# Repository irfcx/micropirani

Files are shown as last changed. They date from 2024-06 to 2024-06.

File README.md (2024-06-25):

# Micropirani vacuum gauge
> [!CAUTION]
>Please bear in mind that this is **NOT** a finished thing, and I even guarantee that it will **NOT** work if you reproduce it
## What is this

This is an indirect vacuum gauge based on the thermal conductivity measuring.
Supposed to be small, cheap and easy to reproduce by using small incandescent bulbs as the pressure sensor

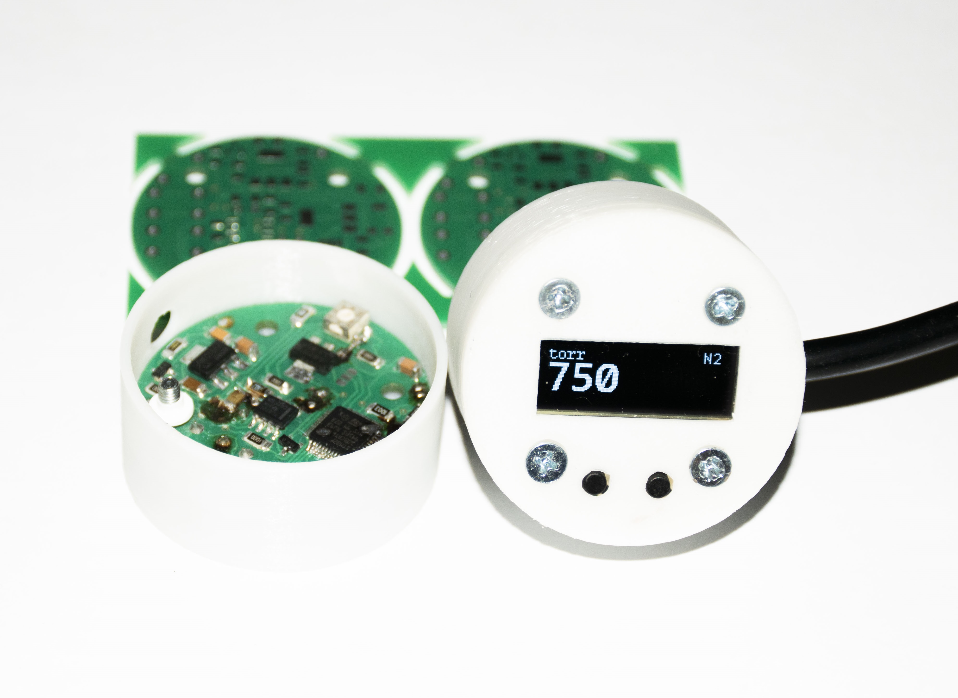
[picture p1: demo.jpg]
demo

## How it (doesn't) works

There are a lot of ways of measuring thermal conductivity, as constant current, constant voltage (or more complex) constant resistance, or even constant power stabilisation with measure of changing values.
In this case the thermal conductivity measure is based on measuring the power required to maintain constant resistance of lamp filament.
The first two (in theory) have drawbacks such as low sensitivity in high vacuum, or increased filament burning when air is rushing into the system quickly, and the last one is too complex, so i stopped on the constant resistance method.

The common CR circuit is a Wheatstone bridge with feedback on the OP. When current flows through the resistors with the same value of resistance, they are equally heated. If for some reason the resistance of one of the resistors changes, the bridge leaves the balance and the operational amplifier compensates this by changing the voltage on the bridge, which in this case is being measured.

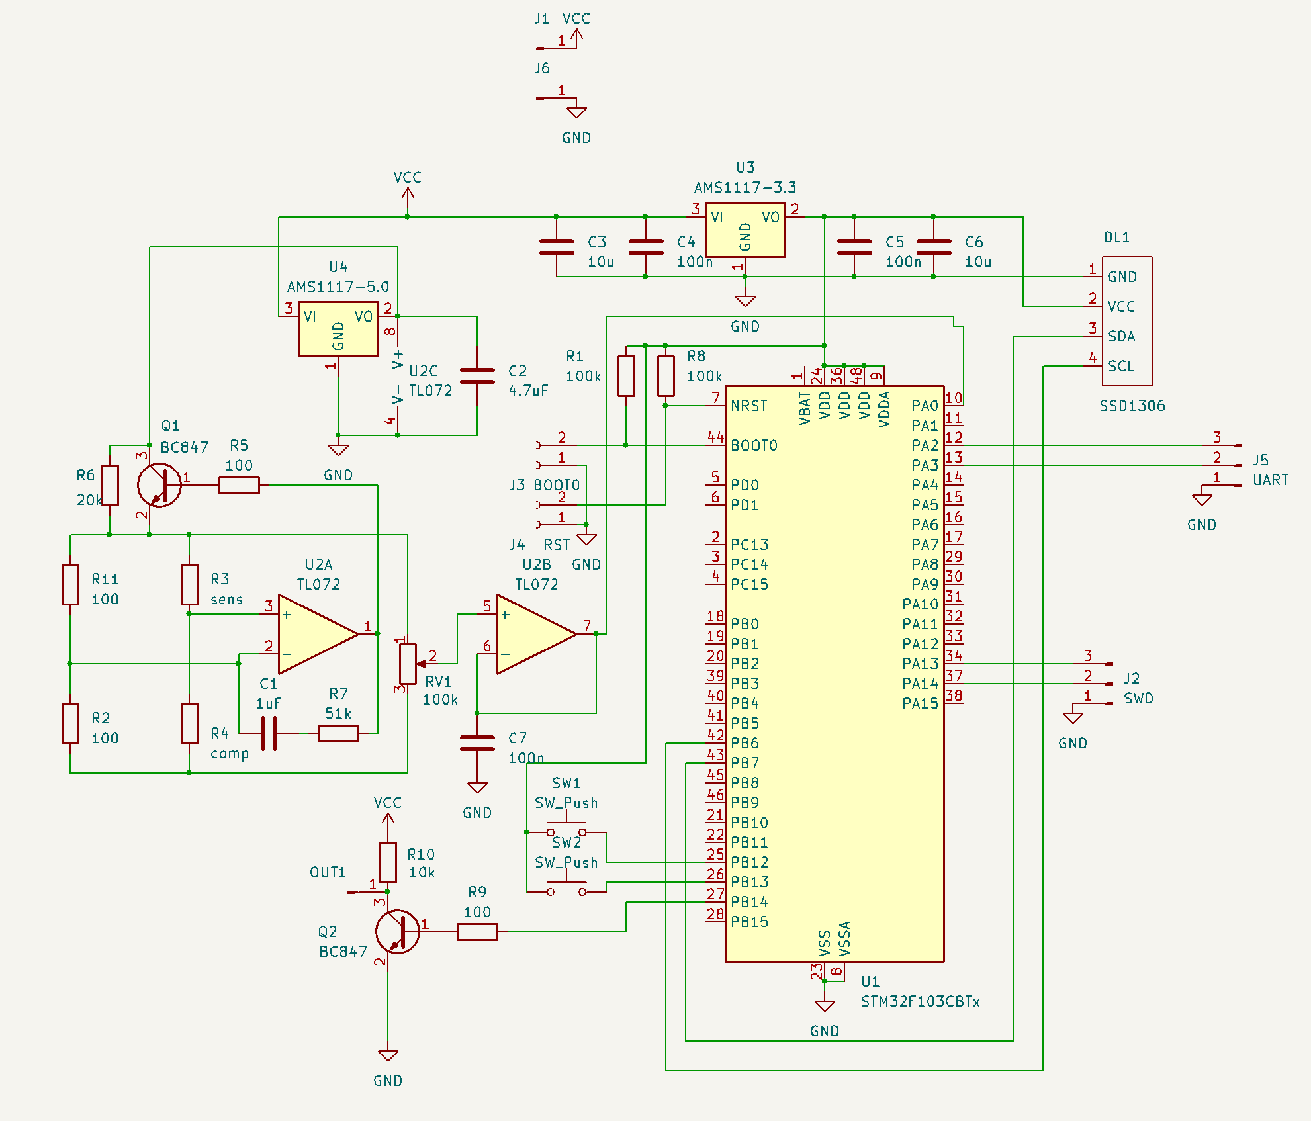
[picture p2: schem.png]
schem


As the thermal conductivity of vacuum is way lower than thermal conductivity of air, resistor (open bulb filament) is cooled less and maintaining a constant resistance requires less voltage.
To compensate the ambient temperature change, a sealed bulb is connected in series to the opened. It should be placed as close as possible to the sealed bulb. The STM32 ADC measures the voltage from the bridge that passes through the buffer (it's necessary due to the limitations of the STM's ADC) and converts it into pressure.

STM32F103CBT6 with 128 kB of flash is used as an MCU. It's also worth noting that no significant optimizations were made to reduce the code size, but the firmware still fits in the any 64 kB chip. However, due to the absence of the EEPROM, its emulation is realised using the last 127th page of the flash memory. This is an important point, because in reality even 64 kB chip has 128 kB of memory, but its operability is not declared or guaranteed by ST, so, when using smaller chips its necessary to correct the addressing.

A typical calibration curve looks like an S-curve turned on the side. However, it was not possible to find coefficients and/or digitize it with some other function, so i used the usual table and linear interpolation between points

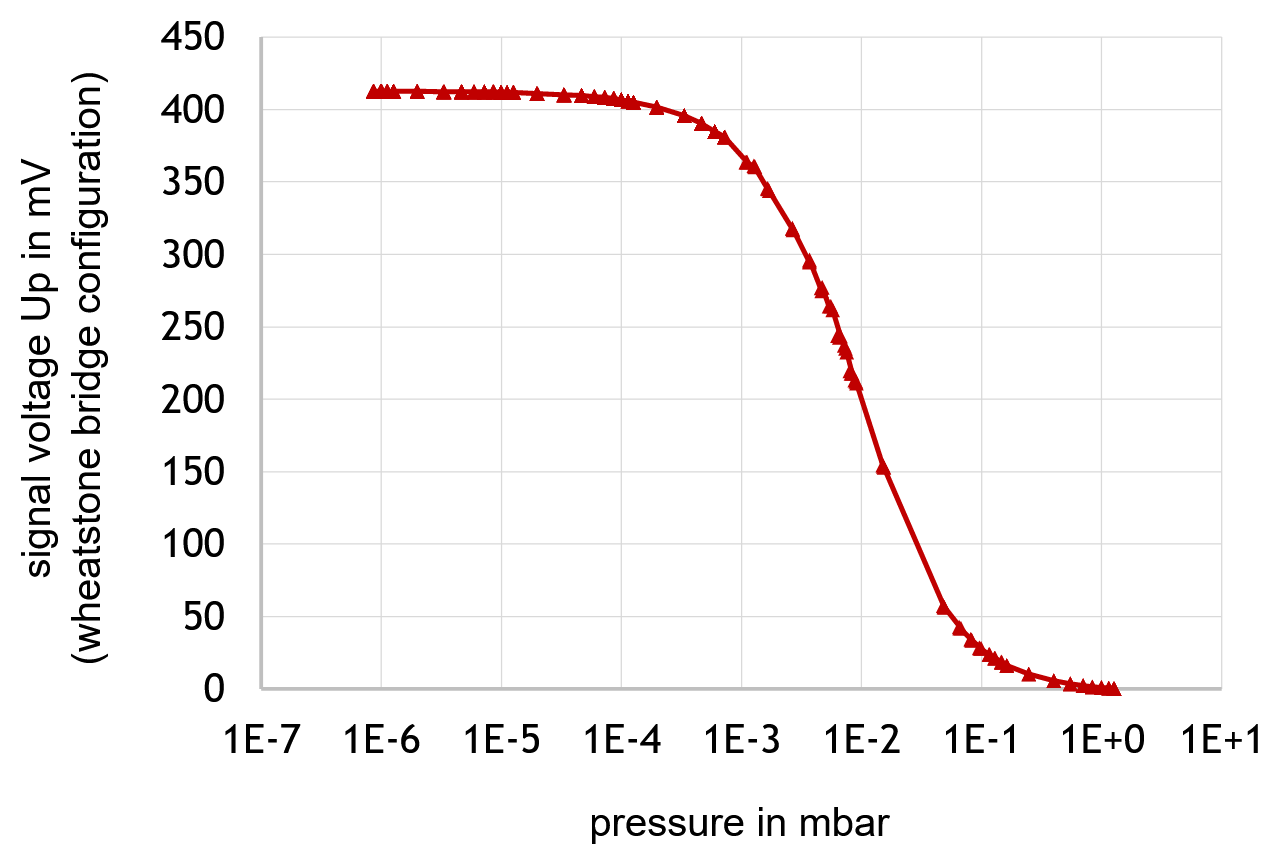
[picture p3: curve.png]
https://www.heimannsensor.com/vacuum-sensing


## Now about the mechanical part

Bulbs are glued to the custom lathe-made KF16 flange from the AISI 316 steel (despite the fact it's still a bottleneck for easy reproducing, you can replace it with cheap KF cap with the hole or whatever you want) using JB weld epoxy, which with that small expose area may be considered suitable for high vacuum

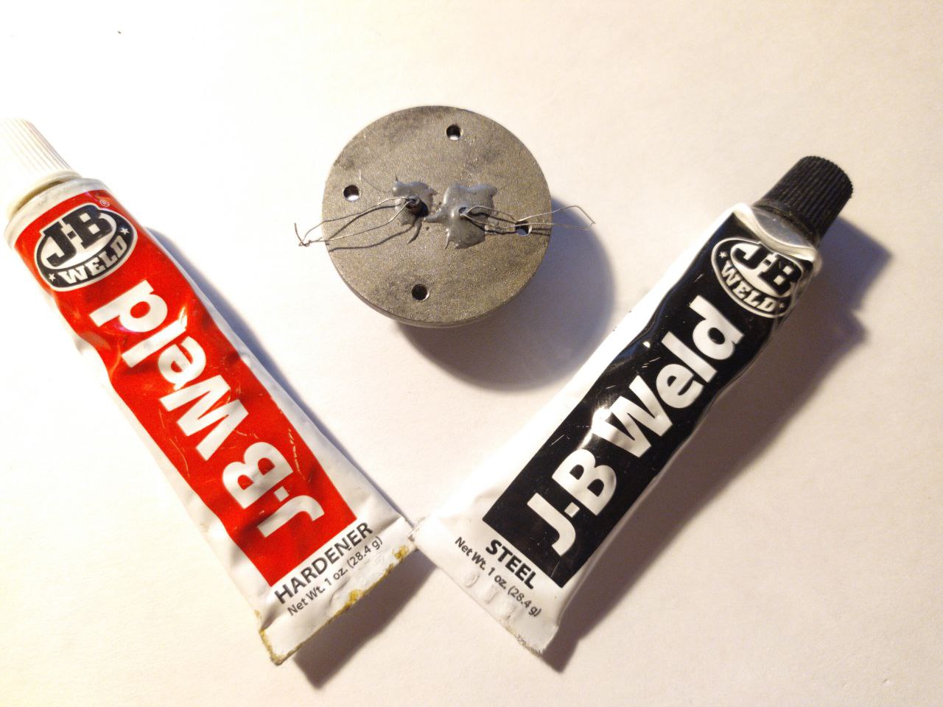
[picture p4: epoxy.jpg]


## Now about what I did wrong (and why THIS device is worse than a usual voltmeter with CC circuit)

 - As it was found experimentally, when common (12V?) light bulbs are used, the bridge voltage is changes only in range from 1.4 to 2.8 volts, which is the less than half of the ADC range, so accuracy is very low (although pirani sensors are not accurate in general), and most importantly, the lower measurement range is limited to approximately 10^-3 torr (when the theoretical limit is 10^-5 torr). As the solution, bipolar power supply for the OP can be made (in the next revision probably)
 - The dumbest thing was the use of two (!) linear voltage stabilizers and putting them in the same pcb with the bridge resistors - their heat (up to 70 C) was enough to heat the resistors so the readings drift over time and the calibration is lost when the supply voltage changes
 - The sealed (thermal compensation) bulb MUST be placed as close as possible to the open one, but for some reason they were separated by the whole centimeter of metal.
 - The lack of EM shielding causes the MCU malfunctioning near the vacuum pump when the frequency converter is used to drive the motor
 - The thickness of the metal base of the flange was insufficient so the ends of the PCB stands stick out

https://github.com/irfcx/micropirani/assets/52609749/1622802e-4848-4f7c-a10b-698a371d4f89

## File location

- Kicad pcb and schematic are located in PCB folder
- The main code is located in /source code/Core/Src/source, the main file is micropirani.h
- The compiled firmware binaries are located in /source code/Release
- In case if someone needs it, the fonts are located in /fonts

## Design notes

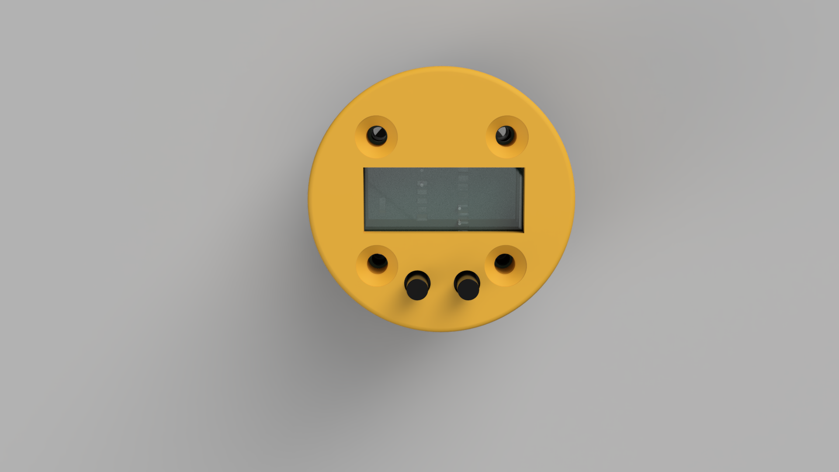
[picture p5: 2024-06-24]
render.PNG

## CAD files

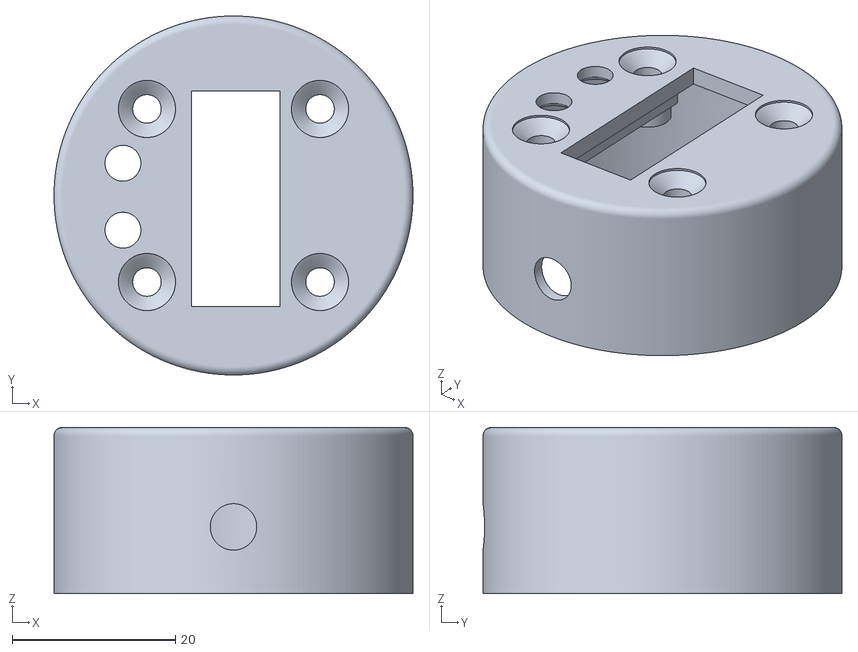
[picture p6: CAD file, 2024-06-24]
stl/Case.stl
44.0 x 44.0 x 20.4

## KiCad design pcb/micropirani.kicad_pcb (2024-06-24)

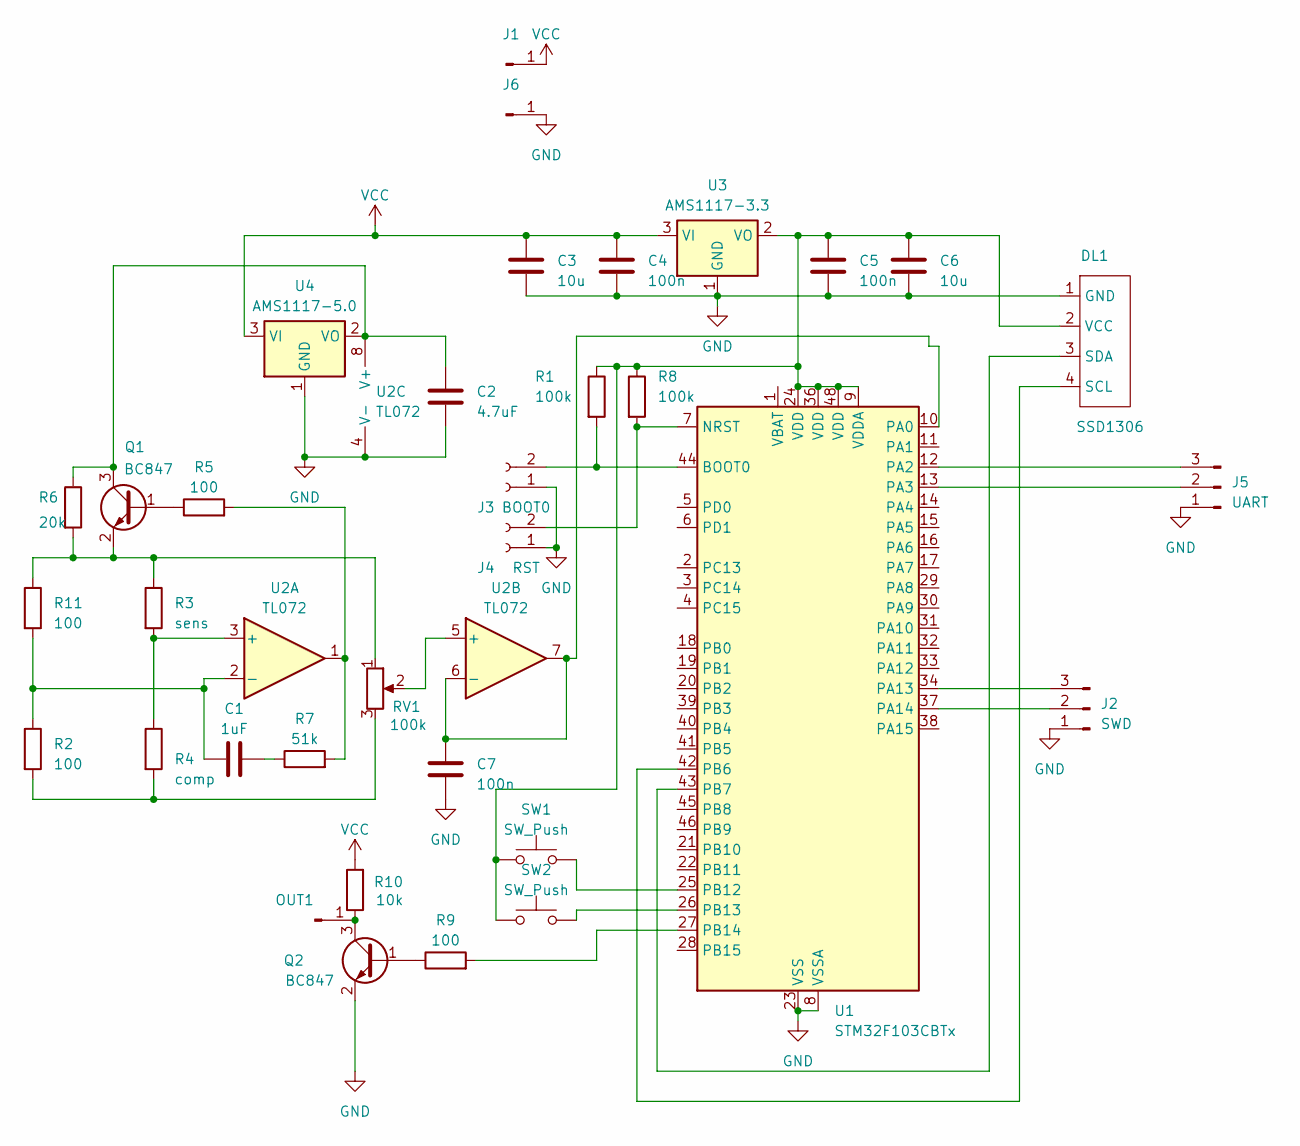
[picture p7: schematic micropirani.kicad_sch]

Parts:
C1: 1uF; C_1206_3216Metric
C2: 4.7uF; C_1206_3216Metric
C3, C6: 10u; C_1206_3216Metric
C4, C5, C7: 100n; C_1206_3216Metric
DL1: SSD1306
J1, J6: Conn_01x01_Pin; TestPoint_THTPad_D2.0mm_Drill1.0mm
J2: SWD; SolderJumper-3_P1.3mm_Open_RoundedPad1.0x1.5mm_NumberLabels
J3: BOOT0; SolderJumper-2_P1.3mm_Open_Pad1.0x1.5mm
J4: RST; SolderJumper-2_P1.3mm_Open_Pad1.0x1.5mm
J5: UART; SolderJumper-3_P1.3mm_Open_RoundedPad1.0x1.5mm_NumberLabels
OUT1: Conn_01x01_Pin; TestPoint_THTPad_D2.0mm_Drill1.0mm
Q1, Q2: BC847; SOT-23
R1, R8: 100k; R_1206_3216Metric
R2, R5, R9, R11: 100; R_1206_3216Metric
R3: sens; R_Axial_DIN0204_L3.6mm_D1.6mm_P2.54mm_Vertical
R4: comp; R_Axial_DIN0204_L3.6mm_D1.6mm_P2.54mm_Vertical
R6: 20k; R_1206_3216Metric
R7: 51k; R_1206_3216Metric
R10: 10k; R_1206_3216Metric
RV1: 100k; Potentiometer_Bourns_3214G_Horizontal
SW1, SW2: SW_Push; SW_PUSH_6mm_H13mm
U1: STM32F103CBTx; LQFP-48_7x7mm_P0.5mm
U2: TL072; SO-8_3.9x4.9mm_P1.27mm
U3: AMS1117-3.3; SOT-223-3_TabPin2
U4: AMS1117-5.0; SOT-223-3_TabPin2

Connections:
GND: C2.1, C3.1, C4.1, C5.1, C6.1, C7.1, DL1.1 (GND), J2.1, J3.1, J4.1, J5.1, J6.1, Q2.2 (E), U1.8 (VSSA), U1.23 (VSS), U1.35 (VSS), U1.47 (VSS), U2.4 (V-), U3.1 (GND), U4.1 (GND)
unnamed: C1.2, R7.1
unnamed: DL1.4 (SCL), U1.42 (PB6)
unnamed: DL1.3 (SDA), U1.43 (PB7)
unnamed: C5.2, C6.2, DL1.2 (VCC), R1.1, R8.1, SW1.1, SW2.1, U1.9 (VDDA), U1.24 (VDD), U1.36 (VDD), U1.48 (VDD), U3.2 (VO)
unnamed: J2.2, U1.37 (PA14)
unnamed: J2.3, U1.34 (PA13)
unnamed: J3.2, R1.2, U1.44 (BOOT0)
unnamed: J4.2, R8.2, U1.7 (NRST)
unnamed: J5.2, U1.13 (PA3)
unnamed: J5.3, U1.12 (PA2)
unnamed: OUT1.1, Q2.3 (C), R10.1
unnamed: Q1.1 (B), R5.1
unnamed: C2.2, Q1.3 (C), R6.1, U2.8 (V+), U4.2 (VO)
unnamed: Q1.2 (E), R3.1, R6.2, R11.1, RV1.1
unnamed: Q2.1 (B), R9.1
unnamed: R2.2, R4.2, RV1.3
unnamed: R5.2, R7.2, U2.1
unnamed: C7.2, U1.10 (PA0), U2.6 (-), U2.7
unnamed: SW1.2, U1.25 (PB12)
unnamed: SW2.2, U1.26 (PB13)
unnamed: R9.2, U1.27 (PB14)
unnamed: R3.2, R4.1, U2.3 (+)
unnamed: C1.1, R2.1, R11.2, U2.2 (-)
unnamed: RV1.2, U2.5 (+)
VCC: C3.2, C4.2, J1.1, R10.2, U3.3 (VI), U4.3 (VI)

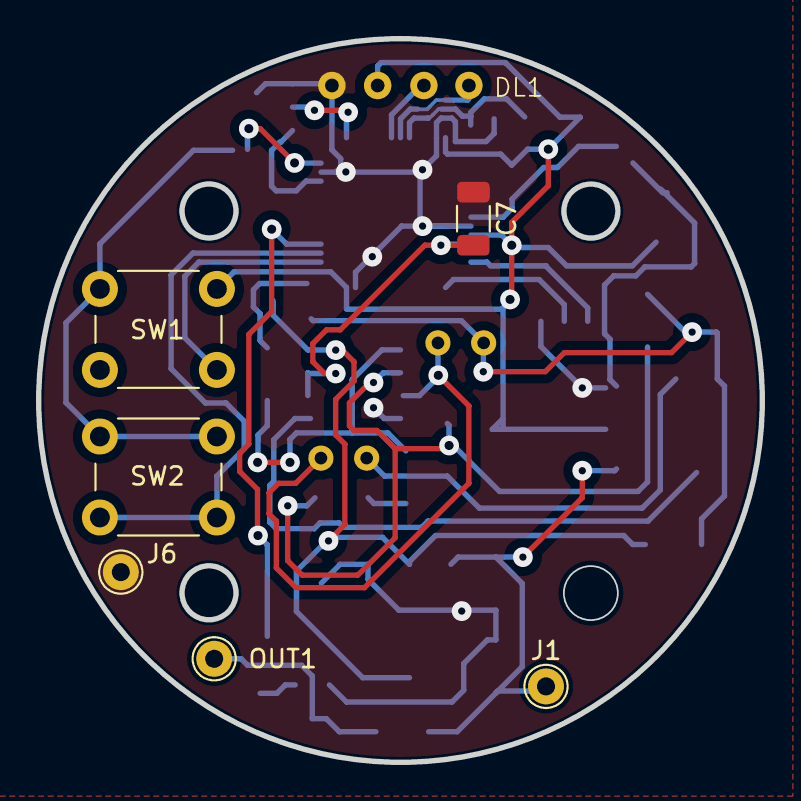
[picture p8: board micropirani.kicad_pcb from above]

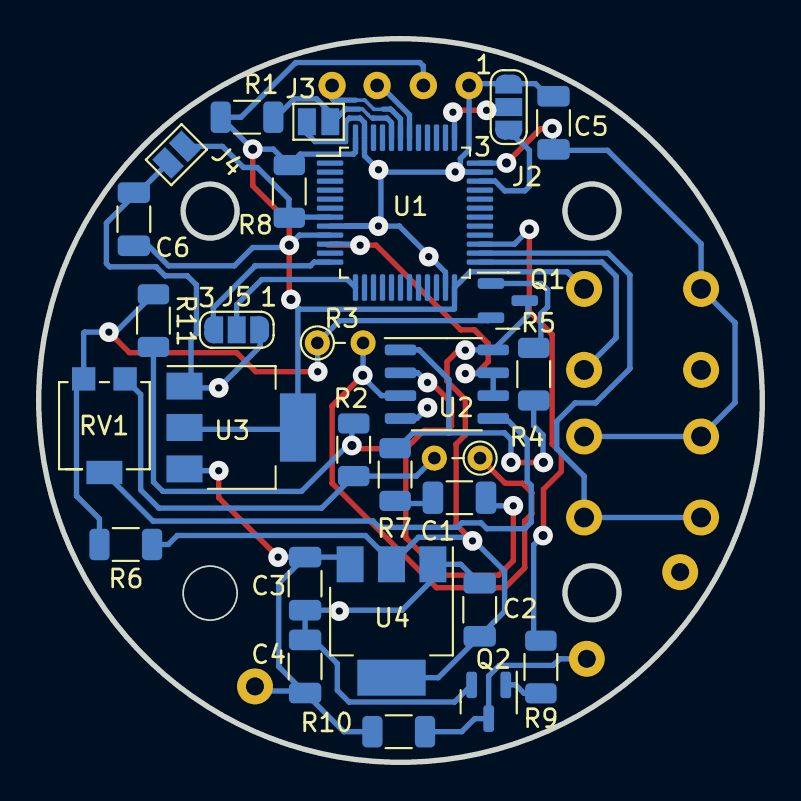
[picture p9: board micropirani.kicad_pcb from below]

Board: 2 copper layers, 40.2 x 40.2 mm, 35 parts (28 on the bottom side), 26 nets.

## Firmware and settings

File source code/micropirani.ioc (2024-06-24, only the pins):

Mcu.UserName=STM32F103RBTx
PA0-WKUP.Signal=ADCx_IN0
PA13.Signal=SYS_JTMS-SWDIO
PA14.Signal=SYS_JTCK-SWCLK
PA2.Signal=USART2_TX
PA3.Signal=USART2_RX
PB12.Signal=GPXTI12
PB13.Signal=GPXTI13
PB14.Signal=GPIO_Output
PB6.Signal=I2C1_SCL
PB7.Signal=I2C1_SDA
PC7.Signal=S_TIM3_CH2

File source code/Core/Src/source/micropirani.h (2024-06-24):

#include "main.h"
#include <stdio.h>
#include <string.h>
#include <stdlib.h>
#include "ssd1306.h"
#include "fonts.h"
#include "eeprom.h" //eeprom emulation library from https://github.com/microtechnics-main/stm32-eeprom-emulation

extern ADC_HandleTypeDef hadc1;
extern TIM_HandleTypeDef htim1;
extern TIM_HandleTypeDef htim2;
extern TIM_HandleTypeDef htim3;
extern UART_HandleTypeDef huart2;

float adc;

int btn1_flag = 0; // left btn
int btn2_flag = 0; // right btn

int btn2_last_state = 0;
int btn2_dur = 0; // btn2 press duration
int btn2_sp_flag; // short press detected
int btn2_lp_flag; // long press detected
int btn2_rise_flag = 0;
int inv_state = 0;


uint32_t adc_zero_val, adc_high_val; // sets during the calibration

// calibration table in range 0-3.3 V / 0-100000 Pa (formatted to float)
float x_cal[70] =
    {
        0.000000, 0.165000, 0.247500, 0.330000, 0.490586, 0.641178, 0.756048, 0.771899, 0.795728, 0.815578, 0.835450, 0.863279, 0.903043, 0.958701, 0.982530, 1.002423, 1.042187, 1.074016, 1.141672, 1.249179, 1.348749, 1.619609, 1.962233, 2.261134, 2.408596, 2.579950, 2.651670, 2.691519, 2.727390, 2.759261, 2.791132, 2.823003, 2.894659, 2.926530, 2.938445, 2.950381, 2.970295, 2.990166, 3.006059, 3.017974, 3.037782, 3.061632, 3.069483, 3.081419, 3.085355, 3.085270, 3.097206, 3.109099, 3.112993, 3.128907, 3.128865, 3.132759, 3.140610, 3.148482, 3.152376, 3.164163, 3.175887, 3.195398, 3.210995, 3.222676, 3.234399, 3.242039, 3.253805, 3.257677, 3.269232, 3.277019, 3.288722, 3.292573, 3.296318, 3.300000
    };

float y_cal[70] =
    {
        0.100000, 0.400000, 0.600000, 1.000000, 2.256220, 5.074364, 9.726596, 10.599673, 11.696064, 12.747622, 13.725196, 15.146896, 17.346120, 21.125771, 23.310944, 24.794148, 28.394086, 31.339410, 38.183390, 50.738388, 64.980503, 125.203718, 276.562082, 520.512820, 709.695243, 1029.341553, 1209.207553, 1318.801300, 1420.692265, 1530.251617, 1648.259843, 1775.368495, 2163.365979, 2330.198008, 2447.746681, 2540.037141, 2668.881849, 2873.549766, 3055.978062, 3210.139281, 3585.000031, 3908.054683, 4257.715098, 4418.249066, 4583.615229, 4812.916657, 4994.384086, 5310.747198, 5645.646505, 5931.235174, 6077.783671, 6461.052815, 7039.134391, 7575.916435, 8053.658844, 9102.635529, 10671.887038, 14139.413380, 17838.714608, 21430.767123, 25125.330477, 30926.318017, 35383.614060, 38076.786554, 49219.220391, 55622.542530, 66012.312876, 71908.974682, 83260.972240, 100000.000000
    };

float linterp(float x, float x1, float y1, float x2, float y2) // linear interpolation, where x - input value, x1 y1 - the beginning, x2 y2 - end
{
    float y = y1 + (y2 - y1) * ((x - x1) / (x2 - x1));
    return y;
}

float convert_p(float voltage, float adc_low, float adc_high)
{
    if (voltage < (adc_low - 50) || voltage > (adc_high + 100))
        return -1; // check if values in range

    float sc_voltage = (voltage - adc_low) * (3.3 / (adc_high - adc_low)); // scaling if the calibration data does not match the table
    if (voltage > adc_high)
        sc_voltage = 3.3; // because the high bound is floating, its better to overwrite too large values, as they are not useful

    float p = 0;
    for (int i = 0; i < 70; i++)
    {
        if (x_cal[i] > sc_voltage)
        {
            p = linterp(sc_voltage, x_cal[i - 1], y_cal[i - 1], x_cal[i], y_cal[i]);
            break;
        }
        if (x_cal[i] == sc_voltage)
        {
            p = y_cal[i];
            break;
        }
    }

    return p;
}

void show_pressure(float p, int units, int gt, int mode) // shows pressure in selected units, gets in torr; mode=0 - show pressure, mode=1 - show setpoint
{
    char disp_bufer[50] = {0};
    char disp_bufer1[20] = {0};
    char units_msg[5];
    float m = 0; // mantiss ?
    int exp = 0; // exponent ?

    float disp_gt[5] = {1.0, 0.67, 1.65, 1.31, 1.12}; // N2 H2 Ar Ne He
    char gas_type[5][3] = {"N2", "H2", "Ar", "Ne", "He"};

    if (p <= 0 && mode == 0) // check if input is correct
    {
        SSD1306_Fill(SSD1306_COLOR_BLACK);
        SSD1306_GotoXY(20, 0);
        sprintf(disp_bufer, "RECAL IS");
        SSD1306_Puts(disp_bufer, &Dot18, SSD1306_COLOR_WHITE);
        SSD1306_GotoXY(30, 16);
        sprintf(disp_bufer, "NEEDED");
        SSD1306_Puts(disp_bufer, &Dot18, SSD1306_COLOR_WHITE);
        SSD1306_UpdateScreen();
        HAL_Delay(300);
        SSD1306_InvertDisplay(1);
        HAL_Delay(300);
        SSD1306_InvertDisplay(0);
        return;
    }

    if(p<=0 && mode == 1)
    {
        sprintf(disp_bufer, "ERROR");
        SSD1306_GotoXY(40, 9);
        SSD1306_Puts(disp_bufer, &Dot18, SSD1306_COLOR_WHITE);
        return;
    }

    p = p * disp_gt[gt]; // true only for low pressure; for high pressure another calibration table is needed (i dont have one)
    switch (units)
    {
    case 0:
        strcpy(units_msg, "torr");
        break;
    case 1:
        p = (p*1.333);
         strcpy(units_msg, "mbar");
        break;
    default:
        break;
    }
    if (p >= 1.0)
    {

        if (p < 9.99)
        {
            memset(disp_bufer, 0, 50);
            sprintf(disp_bufer, "%1.2f", p);
        }

        else if (p < 100)
        {
            memset(disp_bufer, 0, 50);
            sprintf(disp_bufer, "%2.1f", p);
        }

        else
        {
            memset(disp_bufer, 0, 50);
            sprintf(disp_bufer, "%d", (int)p);
        }
        if (mode == 0)
        {
            SSD1306_Fill(SSD1306_COLOR_BLACK);
            SSD1306_GotoXY(0, 6);
            SSD1306_Puts(disp_bufer, &Dot36, SSD1306_COLOR_WHITE);
            SSD1306_GotoXY(0, -1);
            SSD1306_Puts(units_msg, &Dot14, SSD1306_COLOR_WHITE);

            SSD1306_GotoXY(114, -1);
            SSD1306_Puts(gas_type[gt], &Dot14, SSD1306_COLOR_WHITE);
        }
        if (mode == 1)
        {
            if (p<100 || p>1000) SSD1306_GotoXY(43, 9);
            if(p>100 && p<1000) SSD1306_GotoXY(47, 9);
            SSD1306_Puts(disp_bufer, &Dot18, SSD1306_COLOR_WHITE);
        }
    }

    else
    {
        memset(disp_bufer, 0, 50);
        m = p;
        exp = 0;
        while (m < 1)
        {
            m = m * 10.0;
            exp++;
        }
        if (mode == 0)
        {
            sprintf(disp_bufer, "%1.2f", m);
            sprintf(disp_bufer1, "^-%d", exp);
            SSD1306_Fill(SSD1306_COLOR_BLACK);
            SSD1306_GotoXY(0, 6);
            SSD1306_Puts(disp_bufer, &Dot36, SSD1306_COLOR_WHITE);
            SSD1306_GotoXY(45, -1);
            SSD1306_Puts(disp_bufer1, &Dot14, SSD1306_COLOR_WHITE);
            SSD1306_GotoXY(0, -1);
            SSD1306_Puts(units_msg, &Dot14, SSD1306_COLOR_WHITE);
            SSD1306_GotoXY(114, -1);
            SSD1306_Puts(gas_type[gt], &Dot14, SSD1306_COLOR_WHITE);
        }
        if (mode == 1)
        {
            sprintf(disp_bufer, "%1.2f^-%d", m, exp);
            SSD1306_GotoXY(30, 9);
            SSD1306_Puts(disp_bufer, &Dot18, SSD1306_COLOR_WHITE);
        }
    }
}
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
